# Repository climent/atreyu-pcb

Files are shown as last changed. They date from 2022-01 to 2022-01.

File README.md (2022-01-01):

# atreyu-pcb
## Intro 
This project is the evolution of the [Atreyu Keyboard](http://github.com/climent/atreyu) project, an ergonomic keyboard that was handwired only.

I aimed to increase the appeal of this board by designing a PCB for it, and through the next months learned how to design one.

The first release of the keyboard (v0.1) is ready, and looks like this:

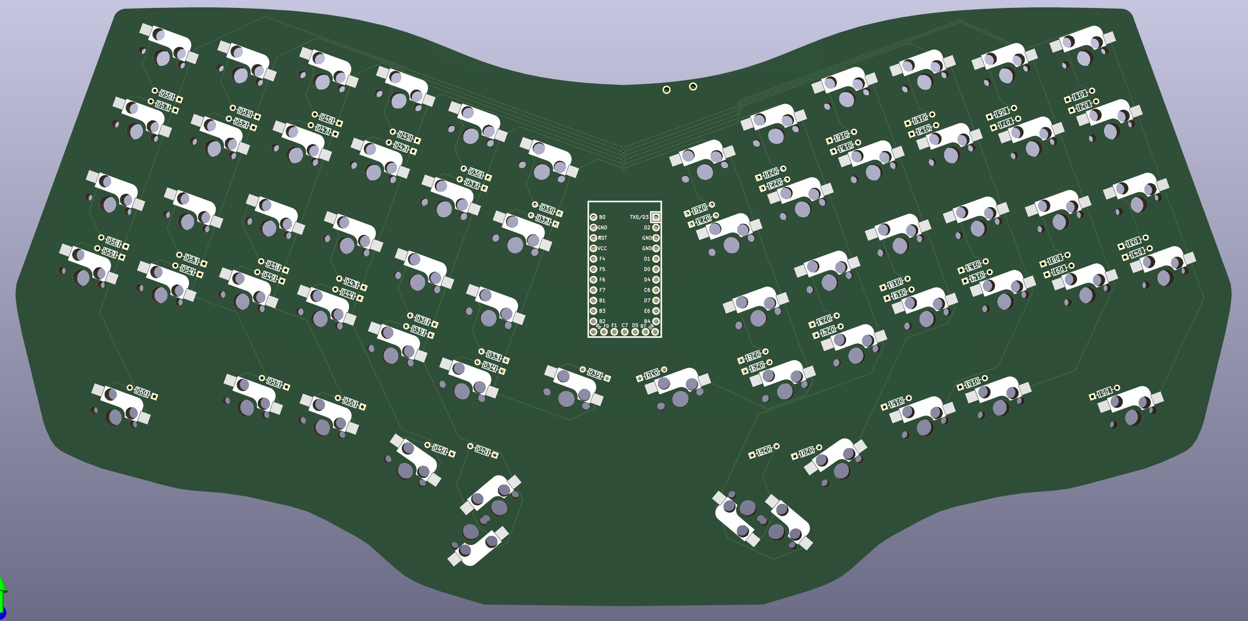
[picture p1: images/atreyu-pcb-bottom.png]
A picture of the Atreyu The Atreyu keyboard


## Want to collaborate?

You can execute

```git clone --recurse-submodules https://github.com/climent/atryeu-pcb.git```

and send me a pull request.

have fun!

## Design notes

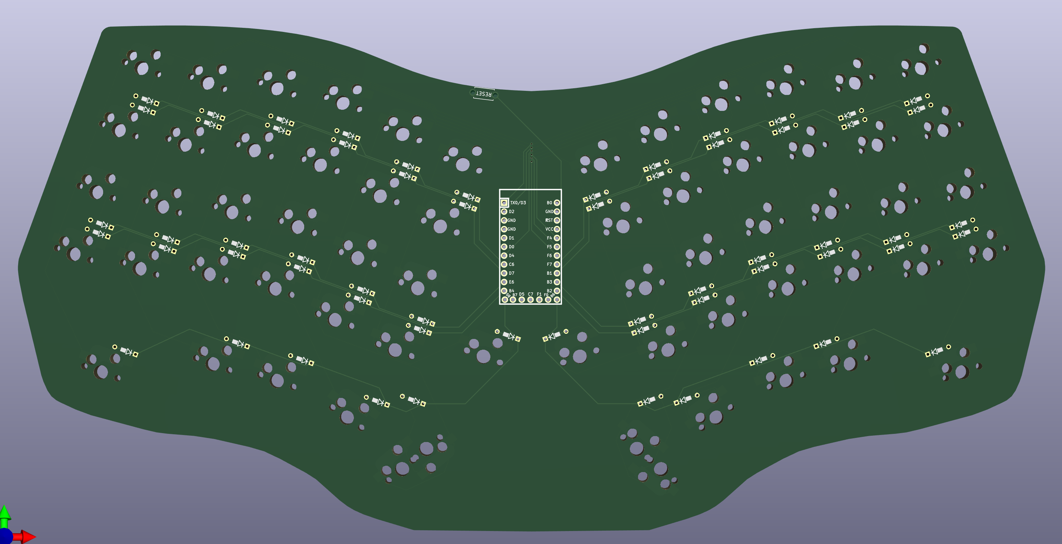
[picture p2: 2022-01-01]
images/atreyu-pcb-top.png

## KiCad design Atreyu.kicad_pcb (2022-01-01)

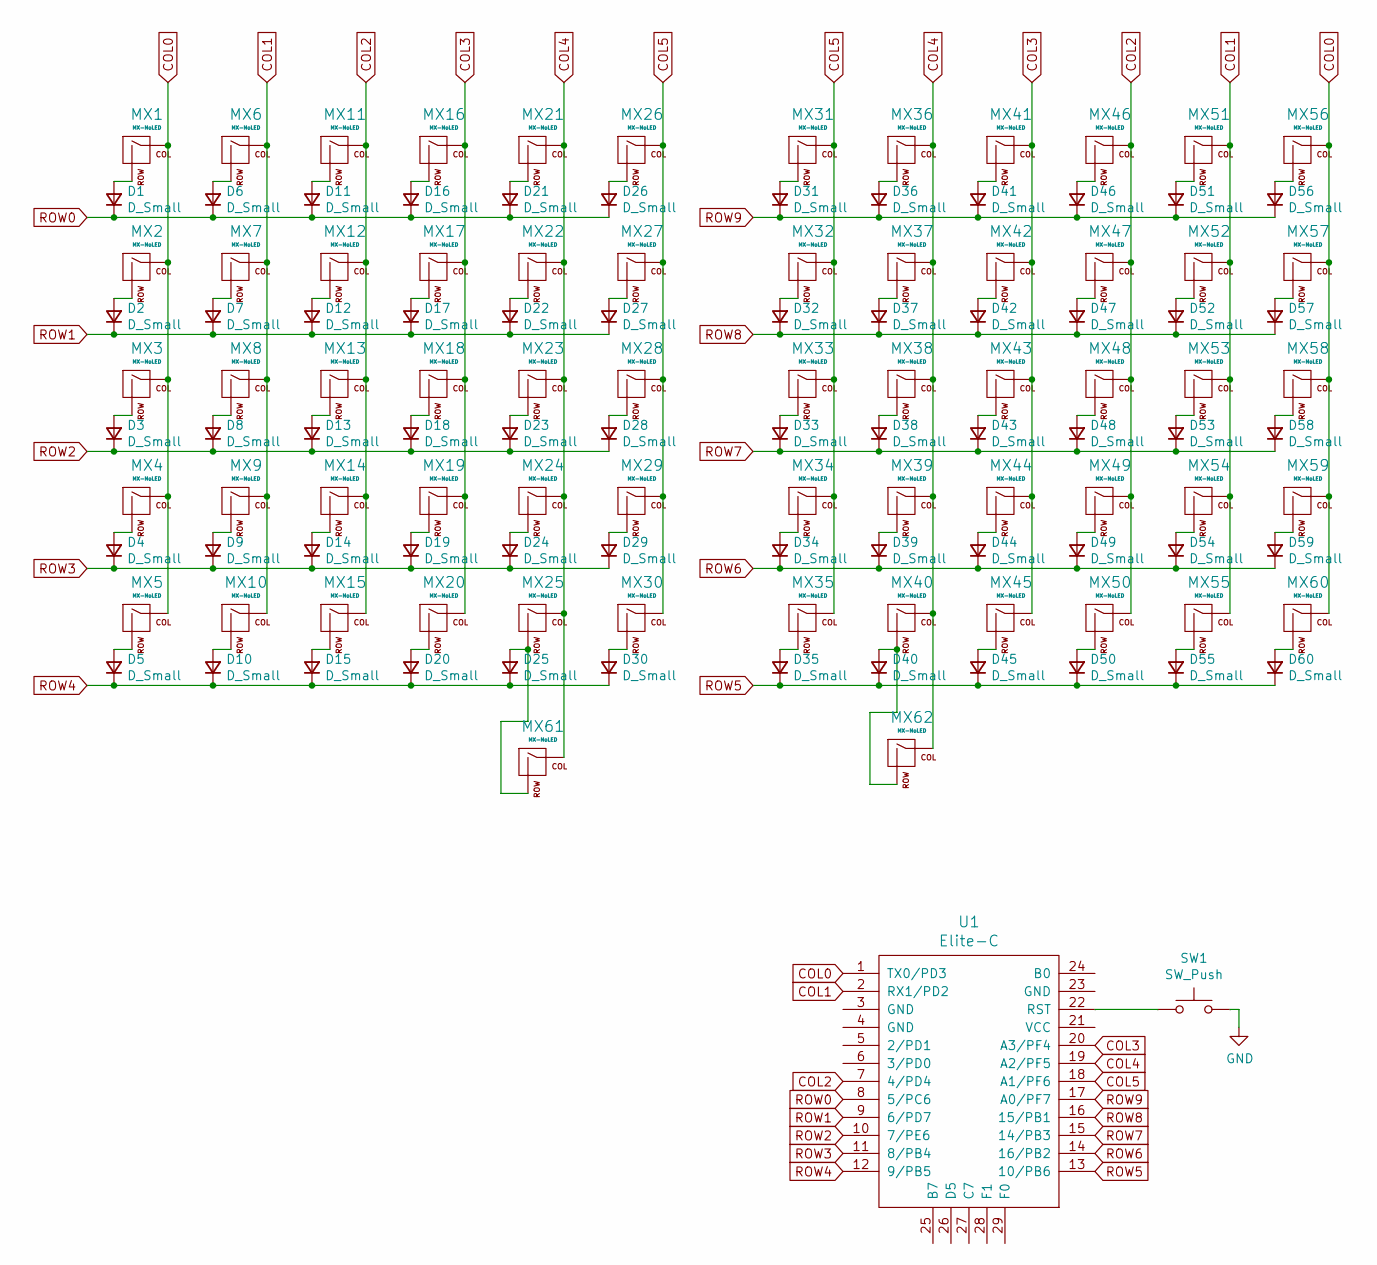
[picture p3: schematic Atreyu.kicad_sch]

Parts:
D1, D2, D3, D4, D5, D6, D7, D8, D9, D10, D11, D12, D13, D14, D15, D16, D17, D18, D19, D20, D21, D22, D23, D24, D25, D26, D27, D28, D29, D30, D31, D32, D33, D34, D35, D36, D37, D38, D39, D40, D41, D42, D43, D44, D45, D46, D47, D48, D49, D50, D51, D52, D53, D54, D55, D56, D57, D58, D59, D60: D_Small; D3_hybrid_common_hole
MX1, MX2, MX3, MX4, MX5, MX6, MX7, MX8, MX9, MX10, MX11, MX12, MX13, MX14, MX15, MX16, MX17, MX18, MX19, MX20, MX21, MX22, MX23, MX24, MX25, MX26, MX27, MX28, MX29, MX30, MX31, MX32, MX33, MX34, MX35, MX36, MX37, MX38, MX39, MX40, MX41, MX42, MX43, MX44, MX45, MX46, MX47, MX48, MX49, MX50, MX51, MX52, MX53, MX54, MX55, MX56, MX57, MX58, MX59, MX60, MX61, MX62: MX-NoLED; CherryMX_Hotswap
SW1: SW_Push; ResetSW_1side
U1: Elite-C

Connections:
COL0: MX1.1 (COL), MX2.1 (COL), MX3.1 (COL), MX4.1 (COL), MX5.1 (COL), MX56.1 (COL), MX57.1 (COL), MX58.1 (COL), MX59.1 (COL), MX60.1 (COL), U1.1 (TX0/PD3)
COL1: MX6.1 (COL), MX7.1 (COL), MX8.1 (COL), MX9.1 (COL), MX10.1 (COL), MX51.1 (COL), MX52.1 (COL), MX53.1 (COL), MX54.1 (COL), MX55.1 (COL), U1.2 (RX1/PD2)
COL2: MX11.1 (COL), MX12.1 (COL), MX13.1 (COL), MX14.1 (COL), MX15.1 (COL), MX46.1 (COL), MX47.1 (COL), MX48.1 (COL), MX49.1 (COL), MX50.1 (COL), U1.7 (4/PD4)
COL3: MX16.1 (COL), MX17.1 (COL), MX18.1 (COL), MX19.1 (COL), MX20.1 (COL), MX41.1 (COL), MX42.1 (COL), MX43.1 (COL), MX44.1 (COL), MX45.1 (COL), U1.20 (A3/PF4)
COL4: MX21.1 (COL), MX22.1 (COL), MX23.1 (COL), MX24.1 (COL), MX25.1 (COL), MX36.1 (COL), MX37.1 (COL), MX38.1 (COL), MX39.1 (COL), MX40.1 (COL), MX61.1 (COL), MX62.1 (COL), U1.19 (A2/PF5)
COL5: MX26.1 (COL), MX27.1 (COL), MX28.1 (COL), MX29.1 (COL), MX30.1 (COL), MX31.1 (COL), MX32.1 (COL), MX33.1 (COL), MX34.1 (COL), MX35.1 (COL), U1.18 (A1/PF6)
GND: SW1.2
unnamed: D1.2 (A), MX1.2 (ROW)
unnamed: D2.2 (A), MX2.2 (ROW)
unnamed: D3.2 (A), MX3.2 (ROW)
unnamed: D4.2 (A), MX4.2 (ROW)
unnamed: D5.2 (A), MX5.2 (ROW)
unnamed: D6.2 (A), MX6.2 (ROW)
unnamed: D7.2 (A), MX7.2 (ROW)
unnamed: D8.2 (A), MX8.2 (ROW)
unnamed: D9.2 (A), MX9.2 (ROW)
unnamed: D10.2 (A), MX10.2 (ROW)
unnamed: D11.2 (A), MX11.2 (ROW)
unnamed: D12.2 (A), MX12.2 (ROW)
unnamed: D13.2 (A), MX13.2 (ROW)
unnamed: D14.2 (A), MX14.2 (ROW)
unnamed: D15.2 (A), MX15.2 (ROW)
unnamed: D16.2 (A), MX16.2 (ROW)
unnamed: D17.2 (A), MX17.2 (ROW)
unnamed: D18.2 (A), MX18.2 (ROW)
unnamed: D19.2 (A), MX19.2 (ROW)
unnamed: D20.2 (A), MX20.2 (ROW)
unnamed: D21.2 (A), MX21.2 (ROW)
unnamed: D22.2 (A), MX22.2 (ROW)
unnamed: D23.2 (A), MX23.2 (ROW)
unnamed: D24.2 (A), MX24.2 (ROW)
unnamed: D25.2 (A), MX25.2 (ROW), MX61.2 (ROW)
unnamed: D26.2 (A), MX26.2 (ROW)
unnamed: D27.2 (A), MX27.2 (ROW)
unnamed: D28.2 (A), MX28.2 (ROW)
unnamed: D29.2 (A), MX29.2 (ROW)
unnamed: D30.2 (A), MX30.2 (ROW)
unnamed: D31.2 (A), MX31.2 (ROW)
unnamed: D32.2 (A), MX32.2 (ROW)
unnamed: D33.2 (A), MX33.2 (ROW)
unnamed: D34.2 (A), MX34.2 (ROW)
unnamed: D35.2 (A), MX35.2 (ROW)
unnamed: D36.2 (A), MX36.2 (ROW)
unnamed: D37.2 (A), MX37.2 (ROW)
unnamed: D38.2 (A), MX38.2 (ROW)
unnamed: D39.2 (A), MX39.2 (ROW)
unnamed: D40.2 (A), MX40.2 (ROW), MX62.2 (ROW)
unnamed: D41.2 (A), MX41.2 (ROW)
unnamed: D42.2 (A), MX42.2 (ROW)
unnamed: D43.2 (A), MX43.2 (ROW)
unnamed: D44.2 (A), MX44.2 (ROW)
unnamed: D45.2 (A), MX45.2 (ROW)
unnamed: D46.2 (A), MX46.2 (ROW)
unnamed: D47.2 (A), MX47.2 (ROW)
unnamed: D48.2 (A), MX48.2 (ROW)
unnamed: D49.2 (A), MX49.2 (ROW)
unnamed: D50.2 (A), MX50.2 (ROW)
unnamed: D51.2 (A), MX51.2 (ROW)
unnamed: D52.2 (A), MX52.2 (ROW)
unnamed: D53.2 (A), MX53.2 (ROW)
unnamed: D54.2 (A), MX54.2 (ROW)
unnamed: D55.2 (A), MX55.2 (ROW)
unnamed: D56.2 (A), MX56.2 (ROW)
unnamed: D57.2 (A), MX57.2 (ROW)
unnamed: D58.2 (A), MX58.2 (ROW)
unnamed: D59.2 (A), MX59.2 (ROW)
unnamed: D60.2 (A), MX60.2 (ROW)
unnamed: SW1.1, U1.22 (RST)
ROW0: D1.1 (K), D6.1 (K), D11.1 (K), D16.1 (K), D21.1 (K), D26.1 (K), U1.8 (5/PC6)
ROW1: D2.1 (K), D7.1 (K), D12.1 (K), D17.1 (K), D22.1 (K), D27.1 (K), U1.9 (6/PD7)
ROW2: D3.1 (K), D8.1 (K), D13.1 (K), D18.1 (K), D23.1 (K), D28.1 (K), U1.10 (7/PE6)
ROW3: D4.1 (K), D9.1 (K), D14.1 (K), D19.1 (K), D24.1 (K), D29.1 (K), U1.11 (8/PB4)
ROW4: D5.1 (K), D10.1 (K), D15.1 (K), D20.1 (K), D25.1 (K), D30.1 (K), U1.12 (9/PB5)
ROW5: D35.1 (K), D40.1 (K), D45.1 (K), D50.1 (K), D55.1 (K), D60.1 (K), U1.13 (10/PB6)
ROW6: D34.1 (K), D39.1 (K), D44.1 (K), D49.1 (K), D54.1 (K), D59.1 (K), U1.14 (16/PB2)
ROW7: D33.1 (K), D38.1 (K), D43.1 (K), D48.1 (K), D53.1 (K), D58.1 (K), U1.15 (14/PB3)
ROW8: D32.1 (K), D37.1 (K), D42.1 (K), D47.1 (K), D52.1 (K), D57.1 (K), U1.16 (15/PB1)
ROW9: D31.1 (K), D36.1 (K), D41.1 (K), D46.1 (K), D51.1 (K), D56.1 (K), U1.17 (A0/PF7)

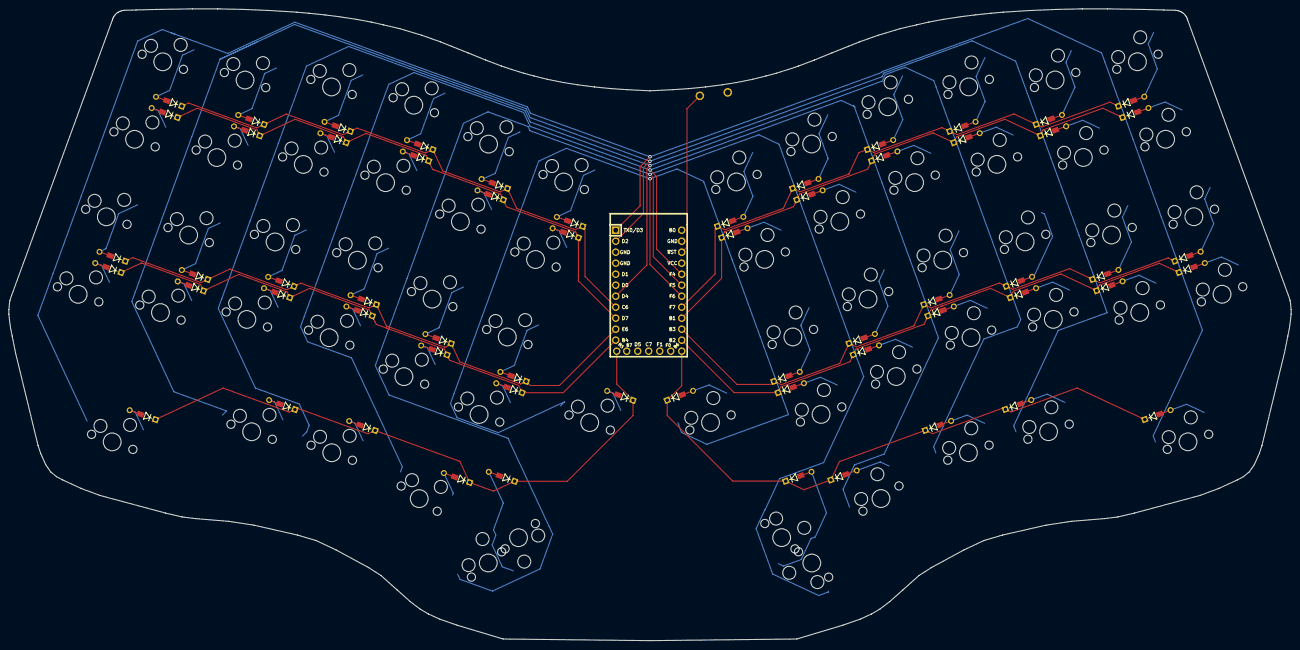
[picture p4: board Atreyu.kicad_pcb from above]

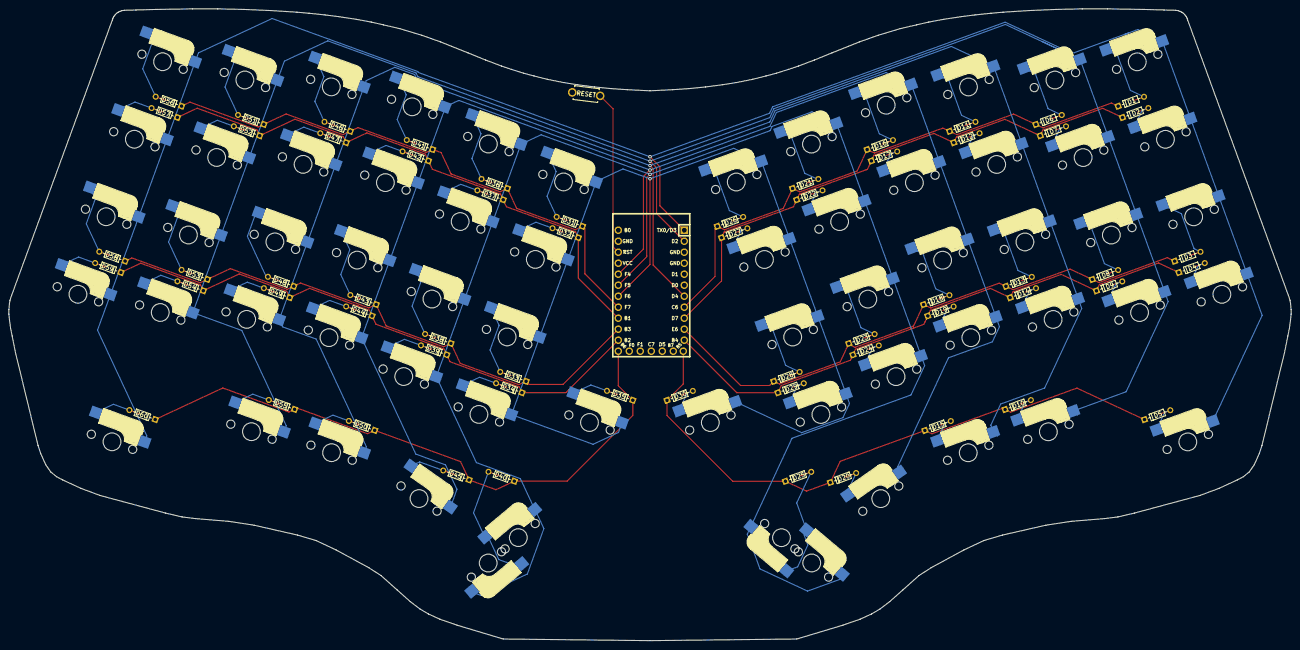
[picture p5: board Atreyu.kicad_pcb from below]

Board: 2 copper layers, 296.2 x 145.9 mm, 124 parts (61 on the bottom side), 77 nets.

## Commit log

2021-06-13 Added keebio submodule and configured libraries for schem and footprint.
    [Atreyu.kicad_pcb, Atreyu.sch]
2021-06-13 Schematic completed.
2021-06-14 PCB initial commit.
    [Atreyu.kicad_pcb, Atreyu.sch]
2021-06-17 Checkpoint commit.
    [Atreyu.kicad_pcb]
2021-06-22 Last update.
    [Atreyu.kicad_pcb]
2021-06-26 Added new symbols/footprints library.
2021-12-30 Tracks routed and sides aligned with the edge cuts layer.
    [Atreyu.kicad_pcb, Atreyu.kicad_sch]
2021-12-31 Created Atreyu local footprint library.
2022-01-01 Completed v0.1.
    [Atreyu.kicad_pcb, Atreyu.kicad_sch]
2022-01-01 Moved reset button to the right and added SVG file with contour.
    [Atreyu.kicad_pcb]
